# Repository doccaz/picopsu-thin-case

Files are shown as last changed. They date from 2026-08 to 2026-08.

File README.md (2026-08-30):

# Thin mATX PicoPSU Case

A fully parametric, 3D-printable case for a micro-ATX motherboard (originally
designed around an ASUS H81M-C), a PicoPSU, and a low-profile CPU cooler —
no expansion cards, as thin as the I/O shield allows.

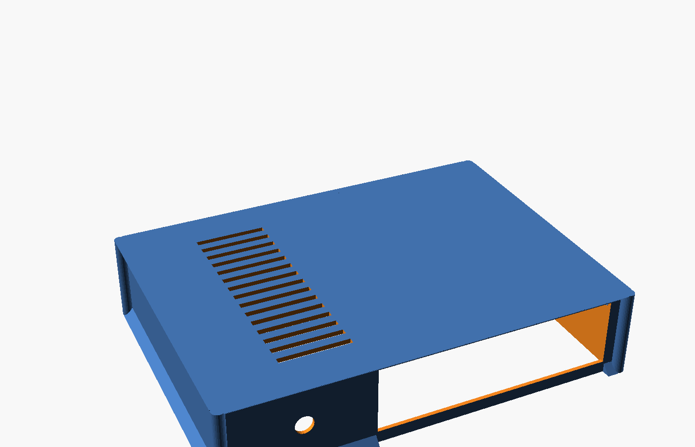
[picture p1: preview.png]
preview


## Real prints

| | |
|---|---|
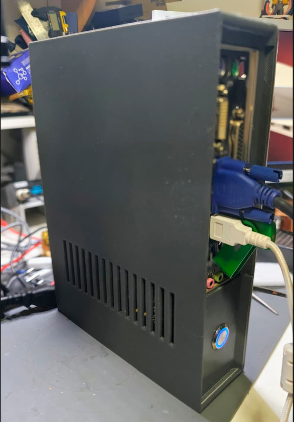
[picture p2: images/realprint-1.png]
real print 1
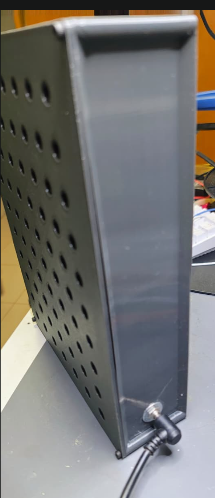
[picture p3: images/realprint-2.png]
real print 2
|  |  |
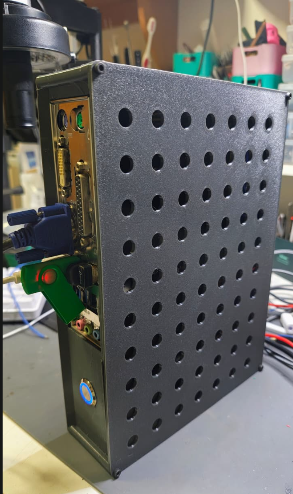
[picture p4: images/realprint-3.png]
real print 3
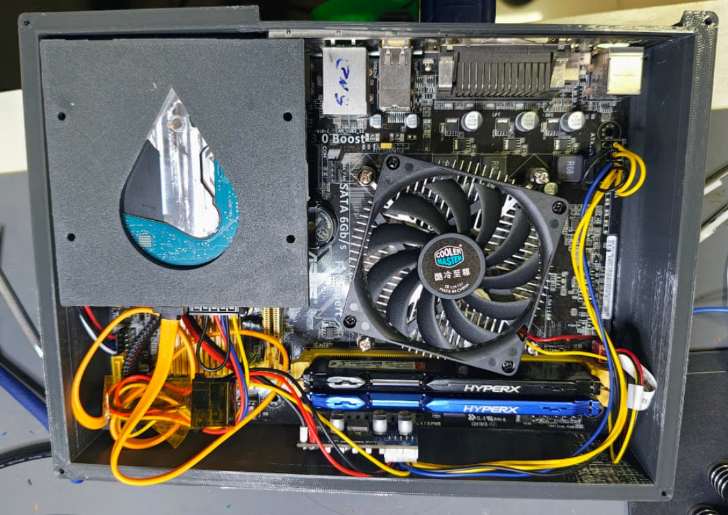
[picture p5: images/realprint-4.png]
real print 4
|  |  |
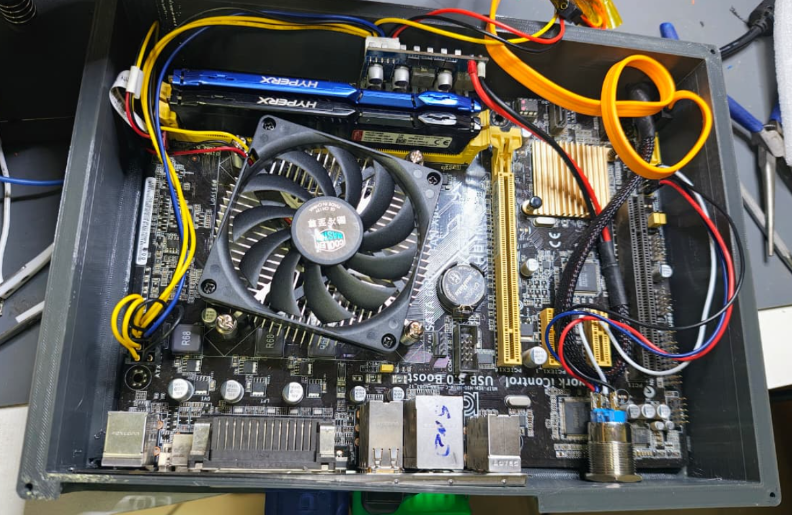
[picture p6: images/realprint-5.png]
real print 5
|  | |

Written as a single [OpenSCAD](https://openscad.org/) file. Every dimension —
board size, wall thickness, I/O shield position, standoff pins, vents, front
panel holes — is a named variable near the top of `case.scad`, so it can be
re-fit to a different board without touching the geometry logic.

## What's included

- **Base tray** — perimeter ledge (widened on one side to match a real
  fit-check), retention tabs, standoff pins across the floor, chamfered
  underside/topside flanges (prints with no supports), rear I/O cutout,
  front DC jack hole, rear power-switch hole, optional floor vents (hex or
  slit style).
- **Lid** — vented, corners rounded to match the screw-post radius.
- **I/O opening test coupon** — a small flat frame with just the I/O cutout,
  for a fast test print before committing to the full tray.
- **Ledge fit test coupon** — a small corner sample (wall + ledge + chamfer +
  retention tab) to test-fit a real board corner before a full print.

Pre-generated STLs for all four are in [`stl/`](stl/). They match whatever
`case.scad` currently contains — regenerate them (see below) after changing
any parameter.

## Printing

Open `case.scad` in OpenSCAD and use the **Customizer** panel (Window menu →
Customizer) to check exactly one of these boxes, then **F6** (Render) →
**File → Export → Export as STL**:

- `show_base`
- `show_lid`
- `show_io_test`
- `show_ledge_test`

Or from the command line:

```sh
openscad -D 'part="base"'       -o base.stl        case.scad
openscad -D 'part="lid"'        -o lid.stl          case.scad
openscad -D 'part="io_test"'    -o io_test.stl      case.scad
openscad -D 'part="ledge_test"' -o ledge_test.stl   case.scad
```

All pieces are oriented to print flat with no supports.

## Fitting to your own board

Everything is driven by named variables at the top of `case.scad`:

| Section | Covers |
|---|---|
| Board dimensions | `board_w`, `board_d`, `board_t`, `gap` |
| Case shell | `wall`, `standoff_h`, `top_clear`, `floor_t`, `lid_t` |
| I/O shield | `shield_w`, `shield_h`, `io_margin_left/right/top/bottom`, `shield_offset_from_board_left`, `rim_above` |
| Ledge / board retention | `ledge_w`, `ledge_w_left`, `ledge_t`, `board_clearance`, `tab_h` |
| Standoff pins | `add_standoff_pins`, `pin_d`, `pin_h`, `pin_pitch`, `pin_margin` |
| Floor vents | `floor_vents`, `floor_vent_style` ("hex"/"slit"), margins, size/pitch |
| Front/rear panel holes | `dc_jack_d/x/z`, `pwr_btn_d/x/z` |
| Corner posts / lid | `ear`, `post_d` |

Re-measure your board's I/O shield position the same way this one was
calibrated: lay a ruler along the rear edge and down the shield height in a
couple of photos, then adjust `shield_offset_from_board_left` and the
`io_margin_*` values to match.

## License

GPL-3.0 — see [LICENSE](LICENSE).

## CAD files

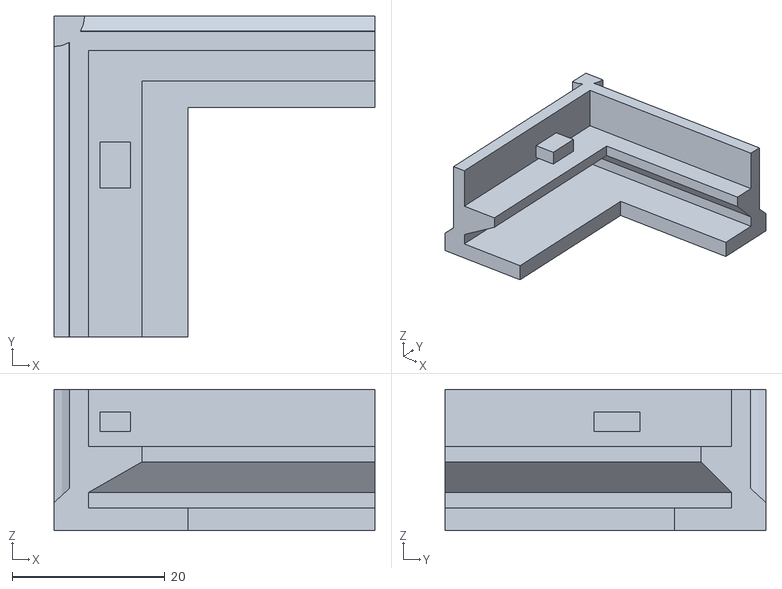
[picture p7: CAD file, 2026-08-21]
stl/ledge_test.stl
42.0 x 42.0 x 18.5

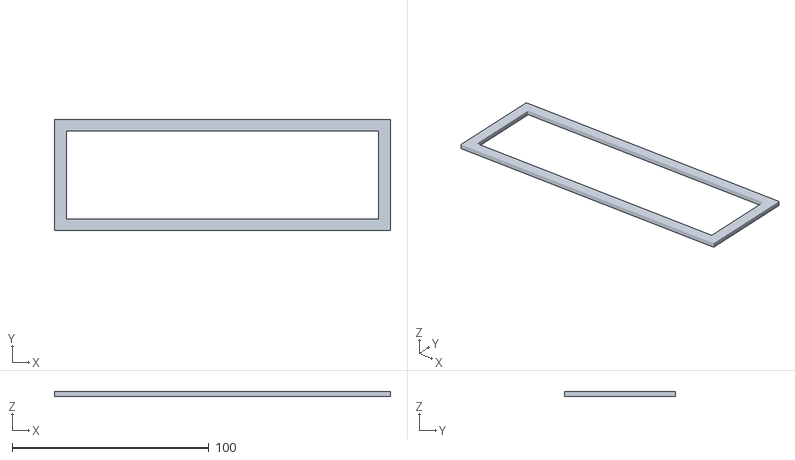
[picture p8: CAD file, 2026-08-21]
stl/io_test.stl
170.8 x 56.5 x 2.50

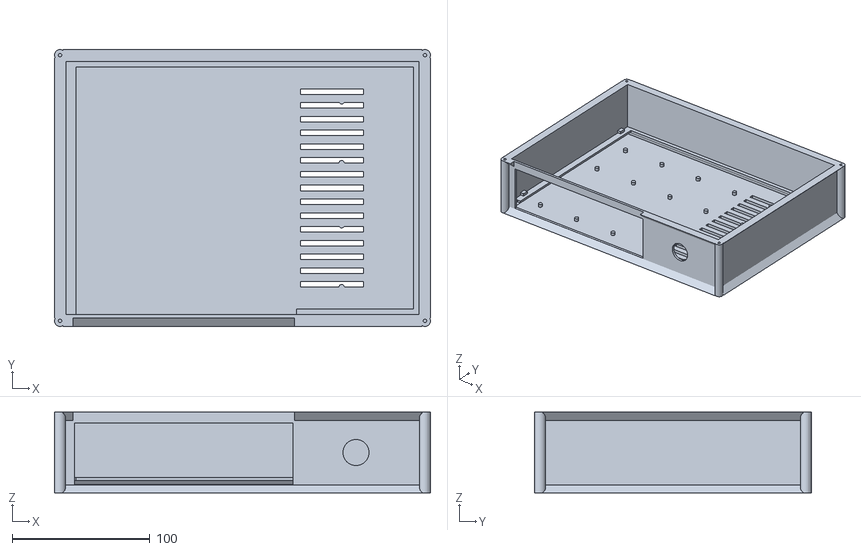
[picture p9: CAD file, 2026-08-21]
stl/base.stl
273.0 x 201.0 x 58.5

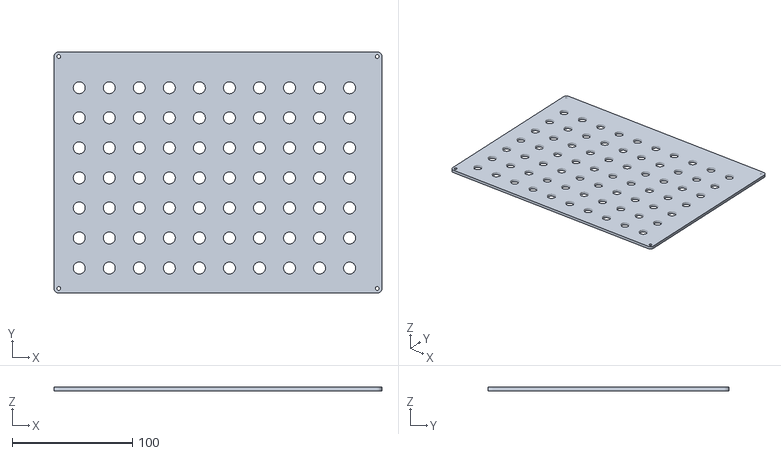
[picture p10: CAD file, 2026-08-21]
stl/lid.stl
273.0 x 201.0 x 3.00

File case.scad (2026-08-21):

// ============================================================
// Thin mATX case for ASUS H81M-C + PicoPSU + low-profile cooler
// ============================================================
// KEY ASSUMPTIONS (verify against your actual board before printing!):
//  - Board: 244 x 178mm (per ASUS manual), standard mATX rear I/O edge
//  - PicoPSU sits vertically on 24-pin, ~25mm tall
//  - Cooler (Hyper H115) is 27mm tall, sits on CPU
//  - No exact mounting-hole coordinates used -- board is retained by a
//    perimeter ledge + snap tabs instead, so it fits regardless of the
//    precise hole pattern. Verify tab positions don't collide with your
//    board's tallest components before printing.
//  - Rear I/O opening sized to standard ATX/mATX shield (158.8 x 44.5mm),
//    OVERSIZED and left as one big rear cutout band -- check/trim to match
//    your board's shield position exactly (measure from your board!).
// ============================================================

$fn = 24;

// ---- core dimensions ----
board_w   = 250;   // along rear edge (X) -- measured from real board
board_d   = 178;   // depth front-to-back (Y)
board_t   = 1.6;

wall      = 2.5;
gap       = 3;      // clearance between board edge and inner wall
ledge_w   = 4;       // width of support ledge board rests on
ledge_w_left = ledge_w + 3;  // left side widened -- board sat with a gap there (see fit-check photo)
ledge_t   = 2;       // thickness of ledge
board_clearance = 0.4;  // slip-fit gap above the board so tabs don't sit flush
tab_h = 2.5;             // catch lip height (how far it overlaps the board)

standoff_h = 6;      // clearance below board for wires/component leads
top_clear  = 30;     // clearance above board top (cooler 27mm + PSU 25mm + margin)
floor_t    = 3;
lid_t      = 3;

ear    = 6;    // how far corner ears poke out past the outer wall
post_d = 8;    // corner post diameter
post_r = post_d/2;

inner_w = board_w + 2*gap;
inner_d = board_d + 2*gap;
outer_w = inner_w + 2*wall;
outer_d = inner_d + 2*wall;

// corner ear anchor points: [post_x, post_y, wall_corner_x, wall_corner_y]
function post_positions() = [
  [-ear+post_r, -ear+post_r, 0, 0],
  [outer_w+ear-post_r, -ear+post_r, outer_w, 0],
  [-ear+post_r, outer_d+ear-post_r, 0, outer_d],
  [outer_w+ear-post_r, outer_d+ear-post_r, outer_w, outer_d]
];

// ---- rear I/O shield opening ----
// Standard ATX/mATX shield bracket is 158.8 x 44.5mm. We size the cutout
// with margin all around so a full shield actually fits and seats cleanly,
// plus a bit of solid wall left above it for strength. This now DRIVES the
// case height -- the shield is taller than the component clearance needs.
shield_w    = 158.8;
shield_h    = 44.5;
// per-side clearance around the shield -- left/bottom fit well already
// (calibrated from photos), right/top had ~4mm too much gap, so those
// are trimmed down independently rather than shrinking all sides equally.
io_margin_left   = 3;
io_margin_right  = -3;  // confirmed by test print -- fits perfectly
io_margin_bottom = 3;
io_margin_top    = -3;  // confirmed by test print -- fits perfectly
rim_above   = 8;               // solid wall kept above the cutout
io_w        = shield_w + io_margin_left + io_margin_right;
io_h        = shield_h + io_margin_bottom + io_margin_top;
io_start_z  = floor_t + standoff_h - io_margin_bottom;

// measured from photos: shield's left edge sits ~6mm in from the board's
// own left edge (NOT centered on the board -- this is normal, the shield
// position is fixed to a corner reference per spec, not the board midpoint)
shield_offset_from_board_left = 6;
board_x0  = wall + gap;                          // board's left edge in case coords
shield_x0 = board_x0 + shield_offset_from_board_left;
io_x0     = shield_x0 - io_margin_left;          // cutout left edge (with margin)
io_x1     = io_x0 + io_w;                        // cutout right edge

case_h_components = floor_t + standoff_h + board_t + top_clear;
case_h_shield      = io_start_z + io_h + rim_above;
case_h  = max(case_h_components, case_h_shield);   // base tray height (to rim)
total_h = case_h + lid_t;

echo("Outer footprint (mm): ", outer_w, " x ", outer_d);
echo("Total height (mm): ", total_h);
echo("Height driven by: ", (case_h_shield > case_h_components) ? "I/O shield" : "component clearance");
echo("I/O cutout left edge (from case left wall): ", io_x0);

// ---- DC jack hole (front wall) -- for the PicoPSU barrel jack.
// Moved to the right side (was left, too close to the RAM slots) and
// resized for a standard 5.5x2.1mm barrel jack panel-mount hole.
dc_jack_d = 8;                // typical picoPSU DC barrel jack cutout
dc_jack_x = outer_w - 20;      // distance from left wall (near right corner now)
dc_jack_z = case_h / 2;        // height (vertically centered)

// ---- power switch hole (rear wall) -- to the right of the I/O shield
pwr_btn_d = 19;
pwr_btn_x = io_x1 + (outer_w - wall - io_x1) / 2;  // centered in the leftover rear-wall strip
pwr_btn_z = case_h / 2;

// ---- floor vents (optional) -- off by default since it opens the case
// to dust; flip floor_vents to true if you want it.
floor_vents       = true;
floor_vent_style  = "slit";  // "hex" (honeycomb holes) or "slit" (rectangular slots)

// margins -- how far the vent pattern is kept from each edge of the floor.
// "front"/"rear" match the same sense as everywhere else in this file
// (rear = the I/O shield side, y=0; front = the open board-insertion side).
floor_vent_margin_left  = 170;
floor_vent_margin_right = 40;
floor_vent_margin_front = 20;
floor_vent_margin_rear  = 20;

// hex style params
floor_vent_d      = 10;   // hex hole size (via cylinder d=, $fn=6)
floor_vent_pitch  = 14;   // spacing between hex centers

// slit style params
floor_vent_slit_w = 4;    // slit height (along Y)
floor_vent_slit_pitch_y = 10;  // spacing between rows (center to center)

// ---- floor standoff pins (optional) -- extra support points across the
// floor so the board doesn't flex in the middle when it's only held at
// the perimeter ledge. On by default; set to false to remove them.
add_standoff_pins = true;
pin_d      = 4;    // pin diameter
pin_h      = 3;    // pin height (ledge/standoff_h is 6, so this sits 3mm proud
                    // of the floor but short of the ledge -- adjust to taste)
pin_pitch  = 45;   // grid spacing
pin_margin = 20;   // keep this far from the walls (clears the ledge/chamfer)

module base_tray() {
  difference() {
    union() {
      // outer shell
      cube([outer_w, outer_d, case_h]);
    }
    // hollow interior
    translate([wall, wall, floor_t])
      cube([inner_w, inner_d, case_h]);

    // rear I/O cutout (rear = y=0 side), sized for a full shield + margin,
    // positioned per the offset measured from the board photos (not centered)
    translate([io_x0, -1, io_start_z])
      cube([io_w, wall+2, io_h]);

    // power switch hole -- rear wall, right of the I/O shield
    translate([pwr_btn_x, -1, pwr_btn_z])
      rotate([-90,0,0])
        cylinder(d=pwr_btn_d, h=wall+2);

    // DC jack hole -- front wall, right side (picoPSU barrel jack)
    translate([dc_jack_x, outer_d+1, dc_jack_z])
      rotate([90,0,0])
        cylinder(d=dc_jack_d, h=wall+2);

    // floor vents -- bounded by the margins above, "hex" or "slit" style
    if (floor_vents) {
      vx0 = wall + floor_vent_margin_left;
      vx1 = wall + inner_w - floor_vent_margin_right;
      vy0 = wall + floor_vent_margin_rear;
      vy1 = wall + inner_d - floor_vent_margin_front;

      if (floor_vent_style == "hex") {
        // honeycomb grid, offset every other row for tight packing
        for (row = [vy0 : floor_vent_pitch*0.87 : vy1 - floor_vent_d]) {
          row_i = round((row - vy0) / (floor_vent_pitch*0.87));
          x_offset = (row_i % 2 == 0) ? 0 : floor_vent_pitch/2;
          for (x = [vx0 + x_offset : floor_vent_pitch : vx1 - floor_vent_d]) {
            translate([x + floor_vent_d/2, row + floor_vent_d/2, -1])
              cylinder(d=floor_vent_d, h=floor_t+2, $fn=6);
          }
        }
      } else if (floor_vent_style == "slit") {
        // parallel full-width slits, like a classic grille
        for (y = [vy0 : floor_vent_slit_pitch_y : vy1 - floor_vent_slit_w]) {
          translate([vx0, y, -1])
            cube([vx1-vx0, floor_vent_slit_w, floor_t+2]);
        }
      }
    }

  }
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

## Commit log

2026-08-21 Initial commit: parametric thin mATX PicoPSU case
    - case.scad: fully parametric OpenSCAD source (base tray, lid, I/O and
    ledge test coupons, selectable via Customizer checkboxes or -D part=)
    - stl/: pre-generated STL exports of all four pieces
    - README.md: usage and fitting-to-your-board guide
    - LICENSE: GPL-3.0
    [base.stl, case.scad, io_test.stl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]
2026-08-30 Add real print photos to README
